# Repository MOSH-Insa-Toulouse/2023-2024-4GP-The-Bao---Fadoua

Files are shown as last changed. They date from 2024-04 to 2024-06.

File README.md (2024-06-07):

# 2023-2024-4GP-The-Bao---Fadoua

# 1. Description du projet  
Notre projet, inscrit dans l'UF "Du capteur au banc de test en open source hardware" de la 4ème année de Génie Physique à l’INSA Toulouse, vise à concevoir, fabriquer et caractériser un capteur de contrainte innovant utilisant une approche low-tech basée sur des capteurs en graphite. S'inspirant des travaux de chercheurs dans le domaine des capteurs, notre objectif est de développer un système de mesure complet, intégrant un shield Arduino avec un circuit analogique incluant un amplificateur transimpédance et des filtres, ainsi qu'une interface utilisateur via un écran OLED et une communication sans fil avec une application Android via un module Bluetooth. Nous avons également créé un banc de test pour évaluer les performances du capteur, en mesurant sa variation de résistance en fonction de la déformation induite par différents crayons graphites. Ces travaux aboutiront à la rédaction d'une datasheet détaillée du capteur, offrant ainsi une solution open source pour la mesure de contraintes basée sur une approche low-tech.

# 2. Livrables 
Les livrables de ce projet sont les suivants :
  
* Circuit Shield PCB avec Arduino UNO
     
   - Schéma électrique du circuit amplificateur transimpédance
   - Conception du PCB réalisée sous KiCad
   - Fabrication du PCB et soudure des composants
   - Intégration des éléments : amplificateur, module Bluetooth, écran OLED, encodeur rotatif
  
* Code Arduino     
   - Développement complet d'un code Arduino pour le fonctionnement du système.
   -  Fonctionnalités incluses :
   - Mesure de la déformation du capteur à base de graphite.
   -Transmission des données via le module Bluetooth.
   - Affichage des mesures sur l'écran OLED.
   - Utilisation de l'encodeur rotatif pour naviguer dans le menu de l'OLED.
  
* Application Android (APK)
* Banc de Test Dédié au Capteur
*  Datasheet Complète du Capteur
 ## 3. Matériel nécessaire
* Carte Arduino UNO
* Amplificateur opérationnel (LTC1050)
* Module Bluetooth (HC-05)
* Écran OLED
* Encodeur rotatif (KY-040)
* Flex Sensor
* 2 Résistance de 100kΩ
* 1 Résistance de 1kΩ
* 1 Résistance de 10kΩ
* Potentiomètre digital MCP-41050
* 2 Condensateurs 100nF
* 1 Condensateurs 1µF

 # 4. Electronique Analogique:
 
Le circuit amplificateur transimpédance est une composante essentielle de notre projet, car il permet de convertir le courant provenant du capteur de déformation à base de graphite en une tension mesurable. Composé de plusieurs éléments interagissant de manière précise, ce circuit garantit des mesures fiables et précises tout au long du processus.

Au cœur du circuit se trouve l'amplificateur opérationnel LTC1050, auquel le capteur de déformation est connecté à l'entrée inverseuse. Ce capteur, conçu pour ajuster sa résistance en fonction de la déformation, induit ainsi un changement de courant à travers la résistance de rétroaction R1.

La précision de nos mesures est assurée par le choix du LTC1050 pour ses faibles valeurs d'offset et de dérive. En complément, nous avons intégré trois étages de filtres au circuit pour optimiser le signal. Un filtre passe-bas à l'entrée (R1,C1) de 16 Hz atténue les hautes fréquences indésirables. Un second filtre passe-bas (R4, C2) de 1,6 Hz élimine le bruit de 50 Hz du réseau électrique. Enfin, un filtre final (R5,C3) de 1,6 kHz traite le bruit de l'ADC pour garantir des mesures précises et stables.



Chaque composant du circuit a été soigneusement sélectionné et dimensionné pour optimiser les performances. Des simulations approfondies sous LTSpice ont validé le fonctionnement du circuit avant la conception du PCB final. Des tests sur une breadboard ont confirmé sa fiabilité en conditions réelles, avec des mesures de résistance et de déformation du capteur réalisées pour évaluer sa précision.

La formule utilisée pour calculer la résistance du capteur de contrainte au graphite est la suivante :

      𝑅𝑠𝑒𝑛𝑠𝑜𝑟 = (1 +𝑅4/𝑅2) ∗ 𝑅1 ∗ (𝑉𝐶𝐶/𝑉𝐴𝐷𝐶) − 𝑅1 − 𝑅3

<h2> Modélisation du capteur:
     
</br>

  

<h2> Voici le schéma du circuit simulé sur le logiciel LTSpice :

</br>

   

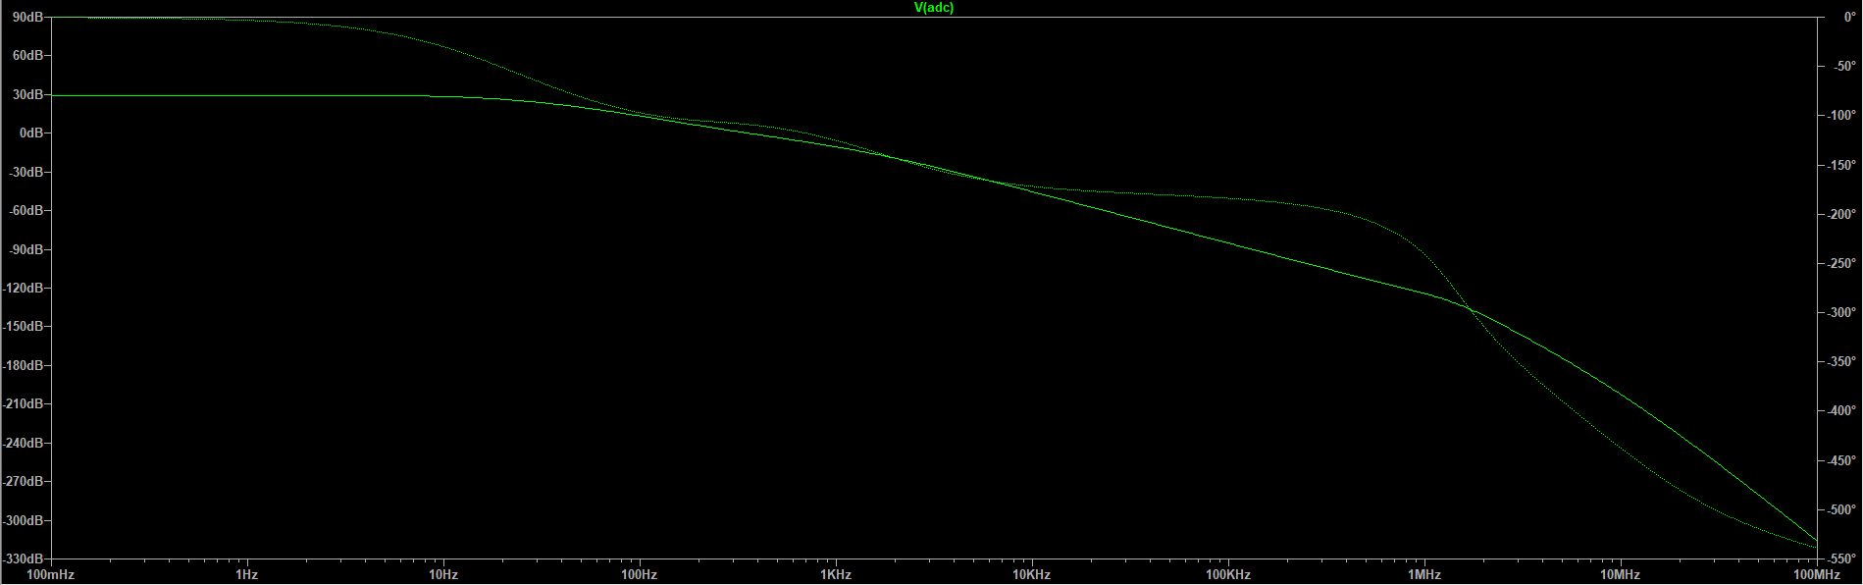
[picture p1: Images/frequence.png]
   
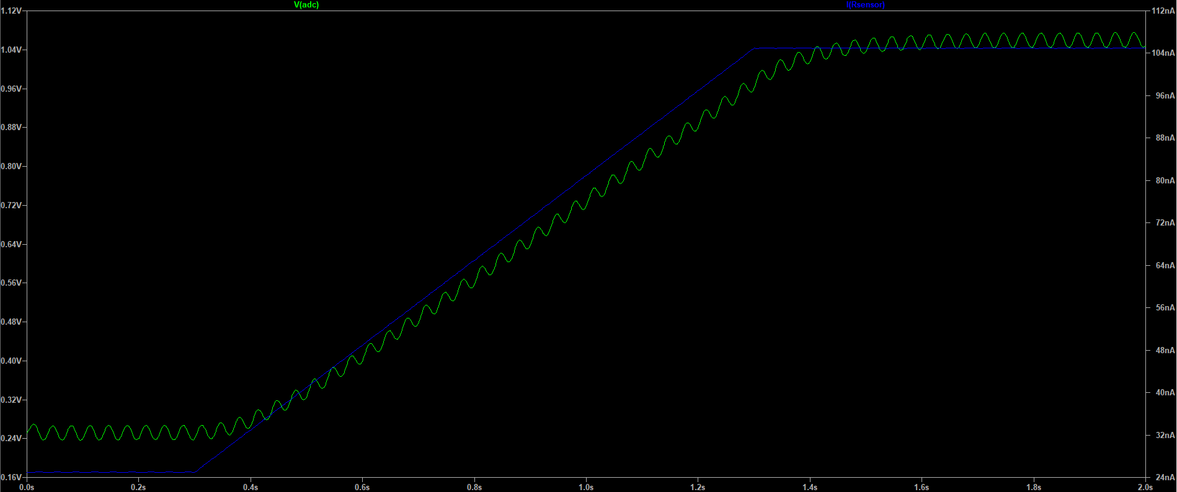
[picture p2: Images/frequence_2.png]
   

 # 5. Progamme Arduino:
 Notre programme d'Arduino nous permet de mesurer la résistance des deux capteurs (Flex sensor et Capteur en graphine) à partir de la valeur tension mesuré par la composant ADC dans l'Arduino. Il affiche ensuite sur l'écran OLED les valeurs de résistance sélectionnées en tournant l'encodeur rotatoire. 

Dans notre programme, on a également établi la connexion entre la module bluetooth et l'application mobile. C'est à dire qu'on a créé les protocols de communication entre eux. Vous pouvez voir dans le diagramme ci-dessous que le module Bluetooth est utilisé pour recevoir les commandes de l'application mobile et lui envoyer les données demandées. L'Arduino va recevoir ces commandes pour envoyer des données à l'application mobile ou régler la résistance du potentiomètre numérique afin de changer le gain de l'amplificateur. 

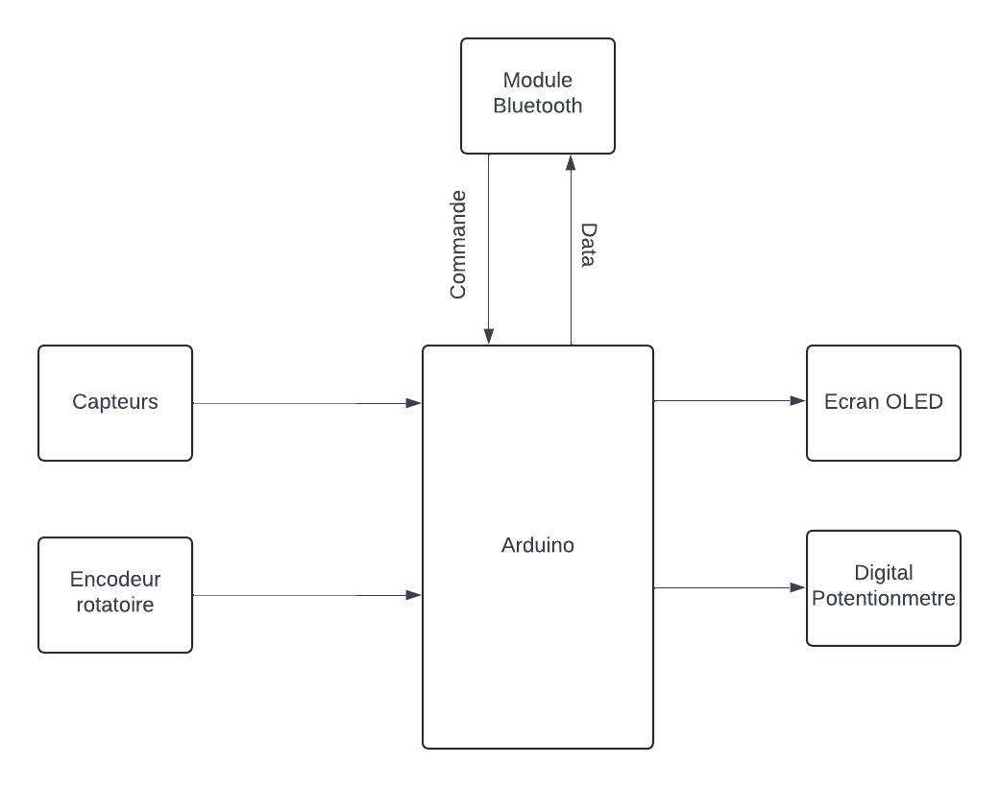
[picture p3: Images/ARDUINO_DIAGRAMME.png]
   

 # 6. KiCad:
 ## Réalisation de la Schématique de Shield
Dans cette étape de réalisation de la schématique du shield, notre objectif principal était de concevoir un circuit électronique fonctionnel pour notre projet. Nous avons choisi le logiciel KiCad comme plateforme de conception et nous nous sommes basés sur le modèle d'une carte Arduino Uno pour assurer la compatibilité. Après avoir identifié tous les composants nécessaires pour notre projet, nous avons ensuite procédé à la création de notre propre bibliothèque d'empreintes personnalisées pour les composants manquants. Cette démarche nous a permis d'adapter notre conception à nos besoins spécifiques et d'assurer une intégration optimale des composants dans notre schéma électrique.
Voici les symboles et empreintes des composants que nous avons créés dans le logiciel KiCad :

### **Module Bluetooth (HC-05)**
  
<div class="column" align="center">

        
</div>

### **Encodeur rotatif (KY-040)**
<div class="column" align="center">

           
</div>

### **Écran OLED**
<div class="column" align="center"> 

             
</div>

### **Flex Sensor**
  <div class="column" align="center">

               
</div>

###  **Potentiomètre digital MCP-41050**

<div class="column" align="center">




</div>

Après avoir créé les schémas et les empreintes pour chaque composant, nous avons assemblé le schéma électrique complet du shield Arduino en reliant les broches des composants avec celles de la carte Arduino.

<div class="column" align="center">

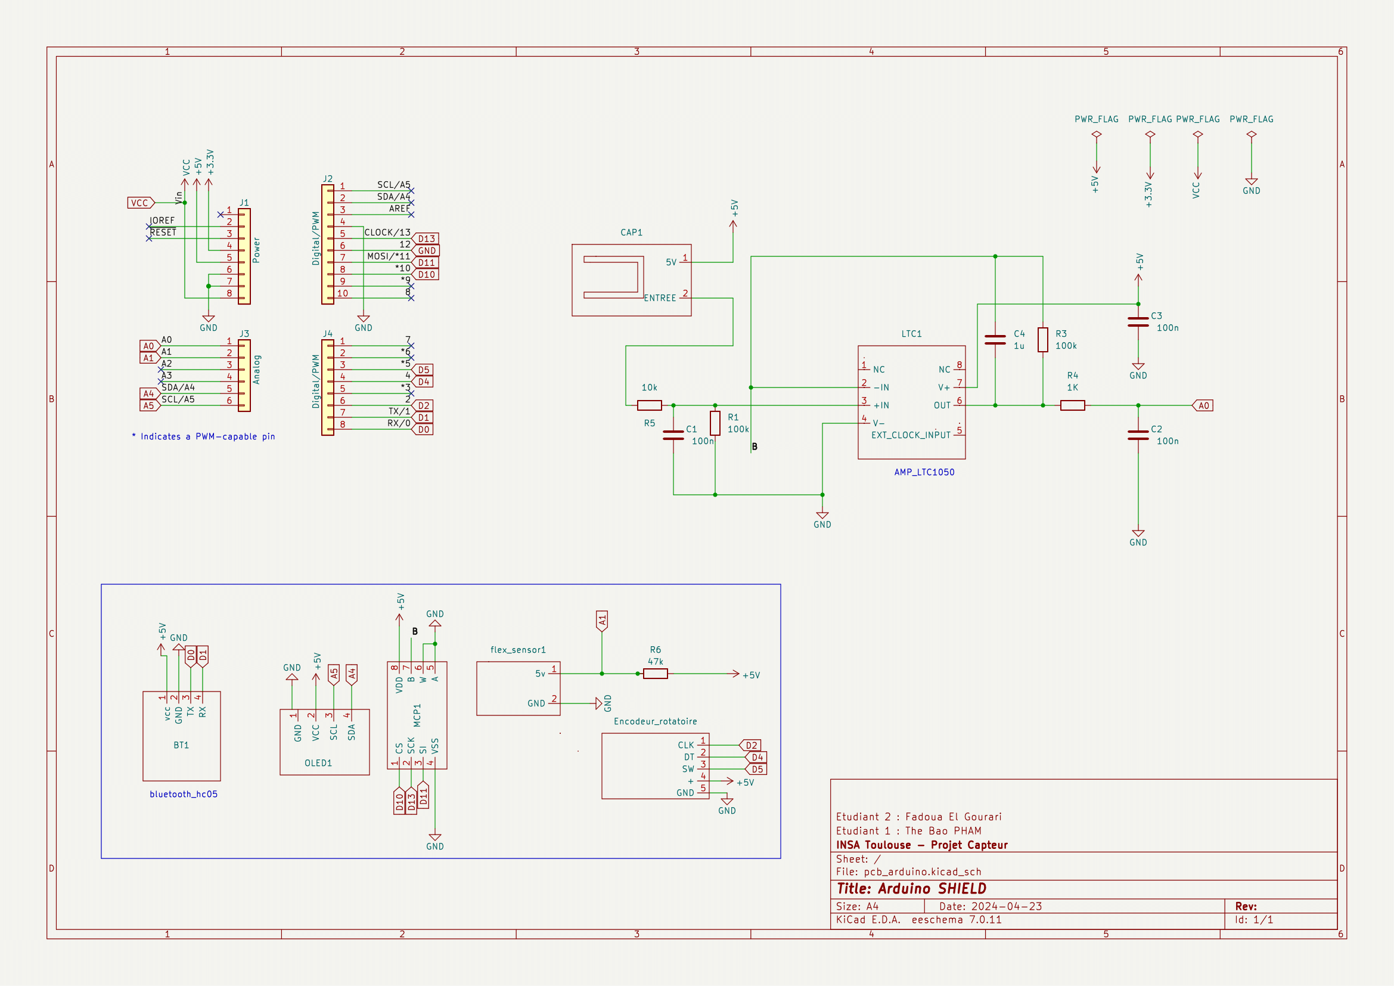
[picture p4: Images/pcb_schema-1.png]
   

</div>

### Réalisation de la Schématique du PCB et visualisation 3D
Dans cette étape, nous avons réalisé le routage de notre circuit en intégrant les composants sur le PCB, tout en veillant à limiter les distances entre les composants et leurs pins, conformément aux directives de nos enseignants référents, M. Jérémie Grisolia et Mme Catherine Crouzet. Nous avons respecté des paramètres spécifiques tels que la largeur des pistes, la largeur d'isolation des pistes et les dimensions des trous pour chaque composant, afin d'assurer la conformité de notre conception. Une fois cette phase terminée, nous avons ajouté le plan de masse pour relier les pistes au GND.

Les paramètres spécifiques suivants ont été respectés :
* Taille du trou de perçage pour l'écran OLED,Flex Sensor,le module Bluetooth et l'encodeur rotatoire, l'AOP et le potentiomètre digital = 1mm
* Taille du trou de perçage pour les résistances et les capacités = 0.8 mm
* Dimensions du trou pour le support de l'AOP ,l'écran OLED,Flex Sensor,le module Bluetooth et l'encodeur rotatoire,le potentiomètre digital (pad n°1 rectangulaire et les autres pins sont ovales) = 2 mm * 2.5 mm
* Largeur d'isolation des pistes = 0.8 mm
* Taille du trou de perçage du via = 0.8 mm
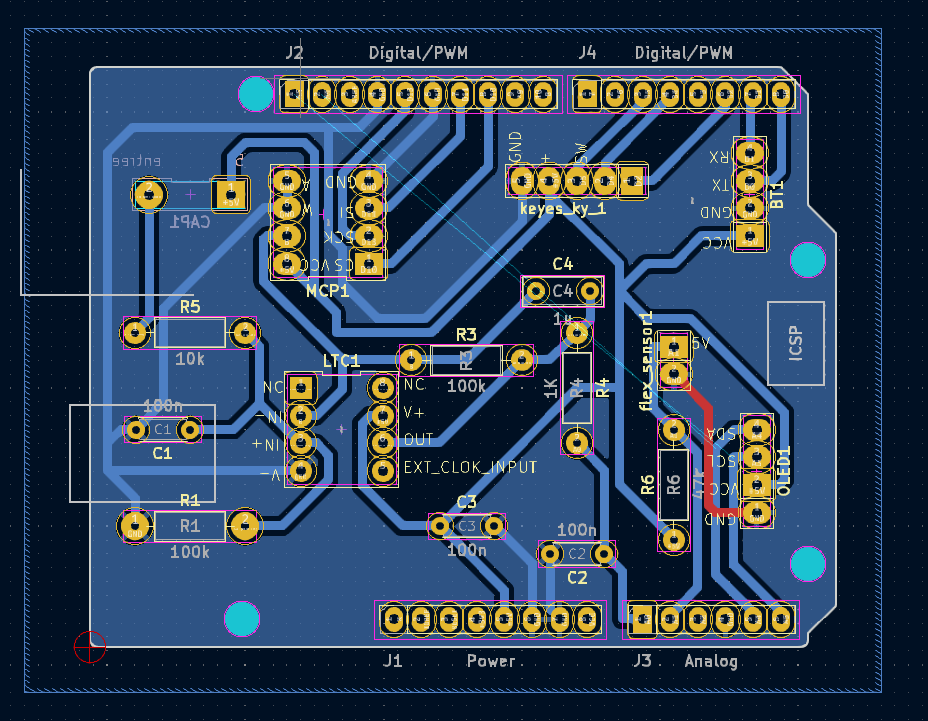
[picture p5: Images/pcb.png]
   

### **Visualisation 3D**
  
Après avoir réalisé le PCB, le téléchargement des modèles de composants sur le site "grabcad.com", qui n'étaient pas fournis par KiCad, s'est avéré très utile. Cela nous a permis d'obtenir un modèle 3D de notre PCB final. Nous avons ainsi pu vérifier que les positions des composants étaient correctes avant de passer à l'étape de l'impression du circuit.
  
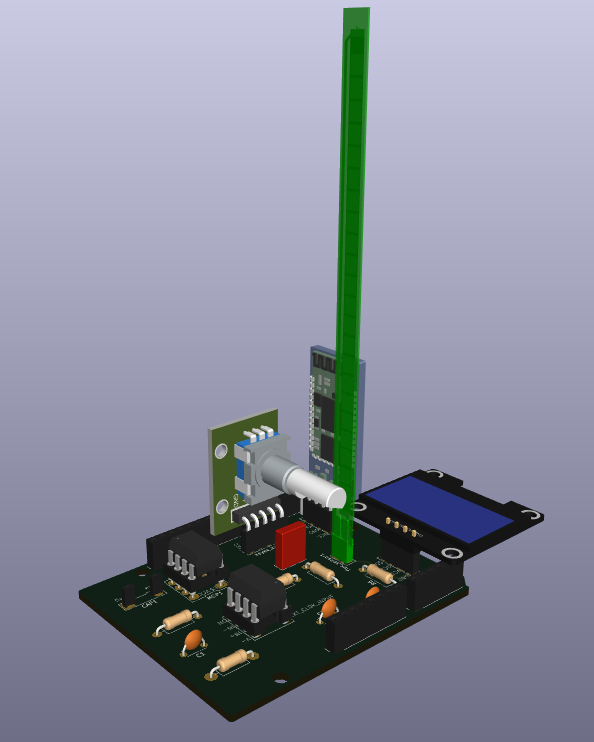
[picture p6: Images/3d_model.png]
  

### **Fabrication du shield PCB:**
  
Dans le cadre de notre projet, nous avons fabriqué un circuit imprimé (PCB) au sein des départements de Génie Électrique et Informatique et de Génie Physique de l'INSA Toulouse. La fabrication a commencé par la modélisation du circuit sur le logiciel KICAD, suivie de l'impression de cette modélisation sur du papier calque. Nous avons ensuite réalisé une insolation UV de notre plaquette d’époxy recouverte d’une fine couche de cuivre (environ 60 µm) pendant une dizaine de minutes, en utilisant le calque comme masque. La résine non exposée aux UV a été retirée avec un révélateur, puis la plaquette a été plongée dans un bain de perchlorure de fer pendant environ 7 à 9 minutes. Cette étape a permis de dissoudre le cuivre non protégé et de révéler les pistes du circuit. Enfin, un rinçage à l'acétone a été effectué pour éliminer les dernières traces de résine, nous permettant ainsi d'obtenir notre PCB conforme à la modélisation initiale. Cette réalisation a été possible grâce à l'aide précieuse de Cathy, assurant la qualité et la précision du produit final.

<div class="column" align="center">

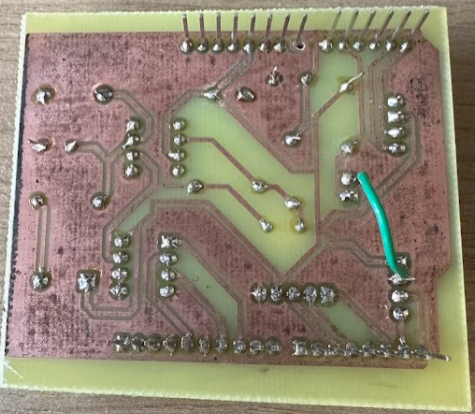
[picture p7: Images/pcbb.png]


 </div>

### Assemblage des composantes :
Une fois le PCB fabriqué, nous avons procédé à l'assemblage des composants, ce qui implique le perçage du PCB et la soudure des éléments électroniques. Conformément aux spécifications de notre projet, deux tailles de trous ont été prévues dans la conception sur KICAD : des trous de 0,8 mm de diamètre pour les composants tels que les amplificateurs opérationnels (AOP) LTC1050, les résistances et les capacités, et des trous de 1 mm de diamètre pour les broches de connexion de la carte Arduino Uno et les headers des différents modules (OLED, Bluetooth, encodeur rotatif...). À l'aide d'une perceuse électrique, nous avons percé le PCB aux emplacements désignés pour insérer les composants. Ensuite, nous avons soudé les composants en place en utilisant de l'étain pour assurer des connexions électriques solides et fiables. Ce processus d'assemblage a permis d'obtenir un shield opérationnel, prêt à être intégré dans notre système.

<div class="column" align="center">


</div>

 # 7. Application mobile:
Pour ce projet, nous avons développé une application mobile sur MIT App Inventor qui se connecte au module Bluetooth du capteur. Cette application dispose d'une interface unique permettant d'acquérir les données du capteur en temps réel, de les visualiser sur un graphique dynamique et de enregistrer le graphique dans notre téléphone ainsi que de régler le gain de l'amplificateur.

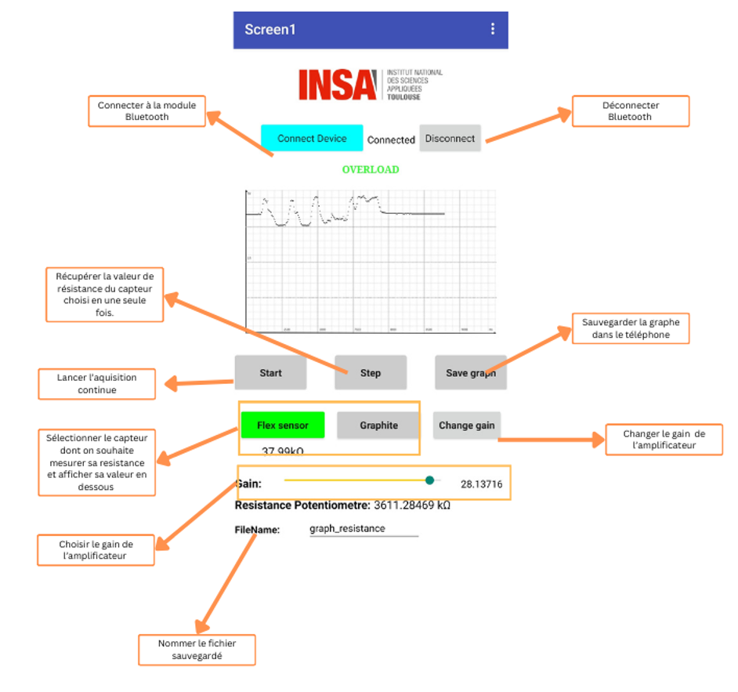
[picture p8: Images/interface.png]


# Initilisation de programme:
<h3>Au début, nous avons déclaré les variable globale utilisé dans le programme de l'application

<br />












Initialiser le programme 

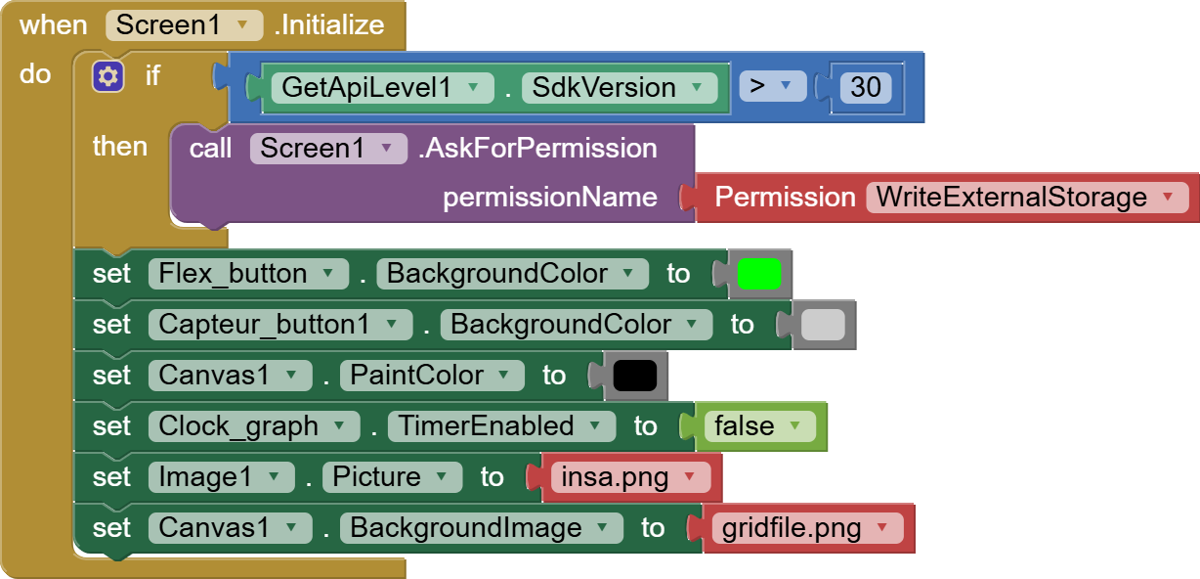
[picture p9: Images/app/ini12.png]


# Composantes dans l'interface:
## "Connect Device" 

Ce bouton est utilisé pour choisir la module bluetooth qu'on veut le connecter


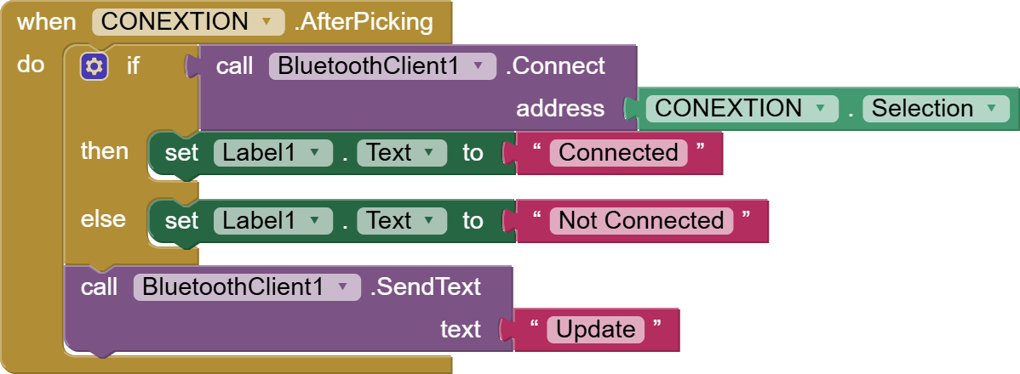
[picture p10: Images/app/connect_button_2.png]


## Statut de connexion bluetooth:
Étiquette représentant la statut de connexion Bluetooth. 

## "Disconnect" 
 Ce bouton est utilisé pour déconnecter la bluetooth.



## Zone graphique
 
On a utilisé la composante "Canvas" dans MIT pour visualiser le signal

Dans cette zone, le signal de tension mesuré est visualisé en fonction du temps. Chaque fois que le potentiel est mesuré, il est représenté par un point sur le graphique.

Concernant le fond du graphique, il est représenté en échelle linéaire. Chaque petit carré correspond à 500 ms en horizontale et à 0,25 V en verticale.

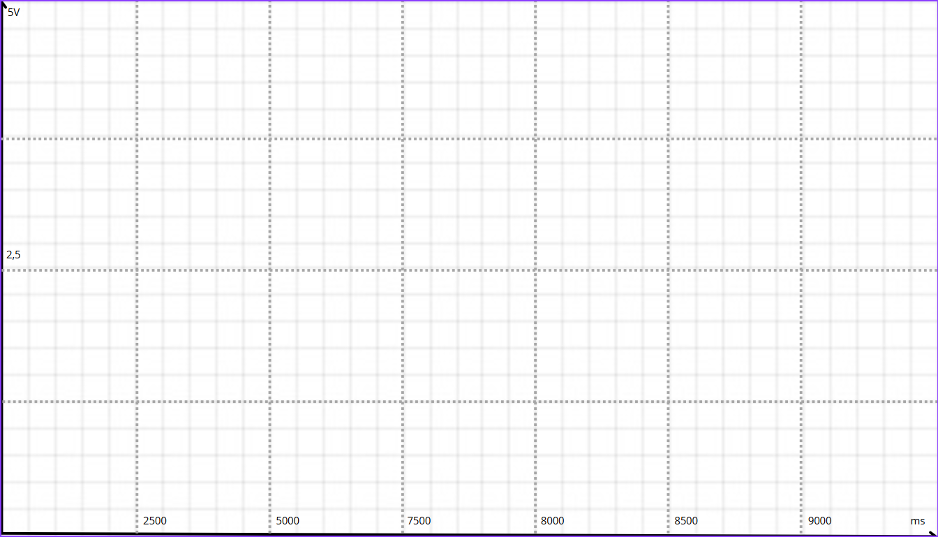
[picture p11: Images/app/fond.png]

Figure 3: Le fond de la graphique

## Statut "Overload"

Parce que, l'Arduino ne mesure que jusqu'à 5V. En outre, avec un gain variable d'ampificatuer, la tension mesurée peut facilement devenir saturée. Ce phénomètre peut être observé lorsque le signal est visualisé dans la graphique. Pourtant, si on prendla valeur de résistance en seul fois, la saturation causerait un mal calcul de la résistance de capteur

Dans notre programme d'Arduino, nous avons défini une limitation de tension mesurée pour éviter la sarturation. La limitation de tension est 0 - 4.8V. Pour pouvoir détecter la saturation, une fois que la tension mesurée dépasse cette limite, l'Arduino vas envoyer un message qui contient une chaine des charactères "over". Si la message recus contien ce mot, l'étiquette "Overload" devient rouge; sinon, elle reste verte.



## "Start"
Lancer l'acquitiion de tension continue avec le délai entre deux acquisitions est 100ms

Une fois ce bouton est appuyé, il désactivera les boutons restants pour éviter d'être pressé par erreur et d'affecter l'acquisition. Pour arrêter l'acquisition, appuyez une nouvelle fois sur ce bouton.

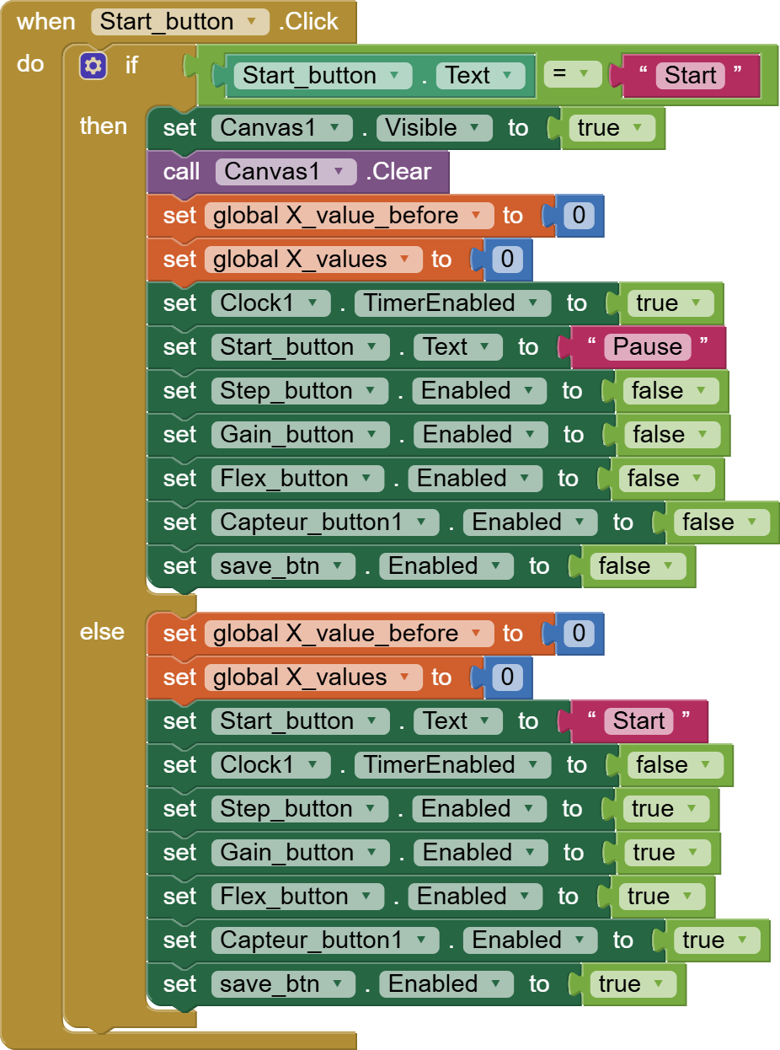
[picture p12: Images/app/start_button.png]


Pour pouvoir récupérer automatiquement des données, nous commandons séquentiellement Arduino de nous evoyer les données. Pour cela, nous avons utilisé le composante "Clock"dans MIT

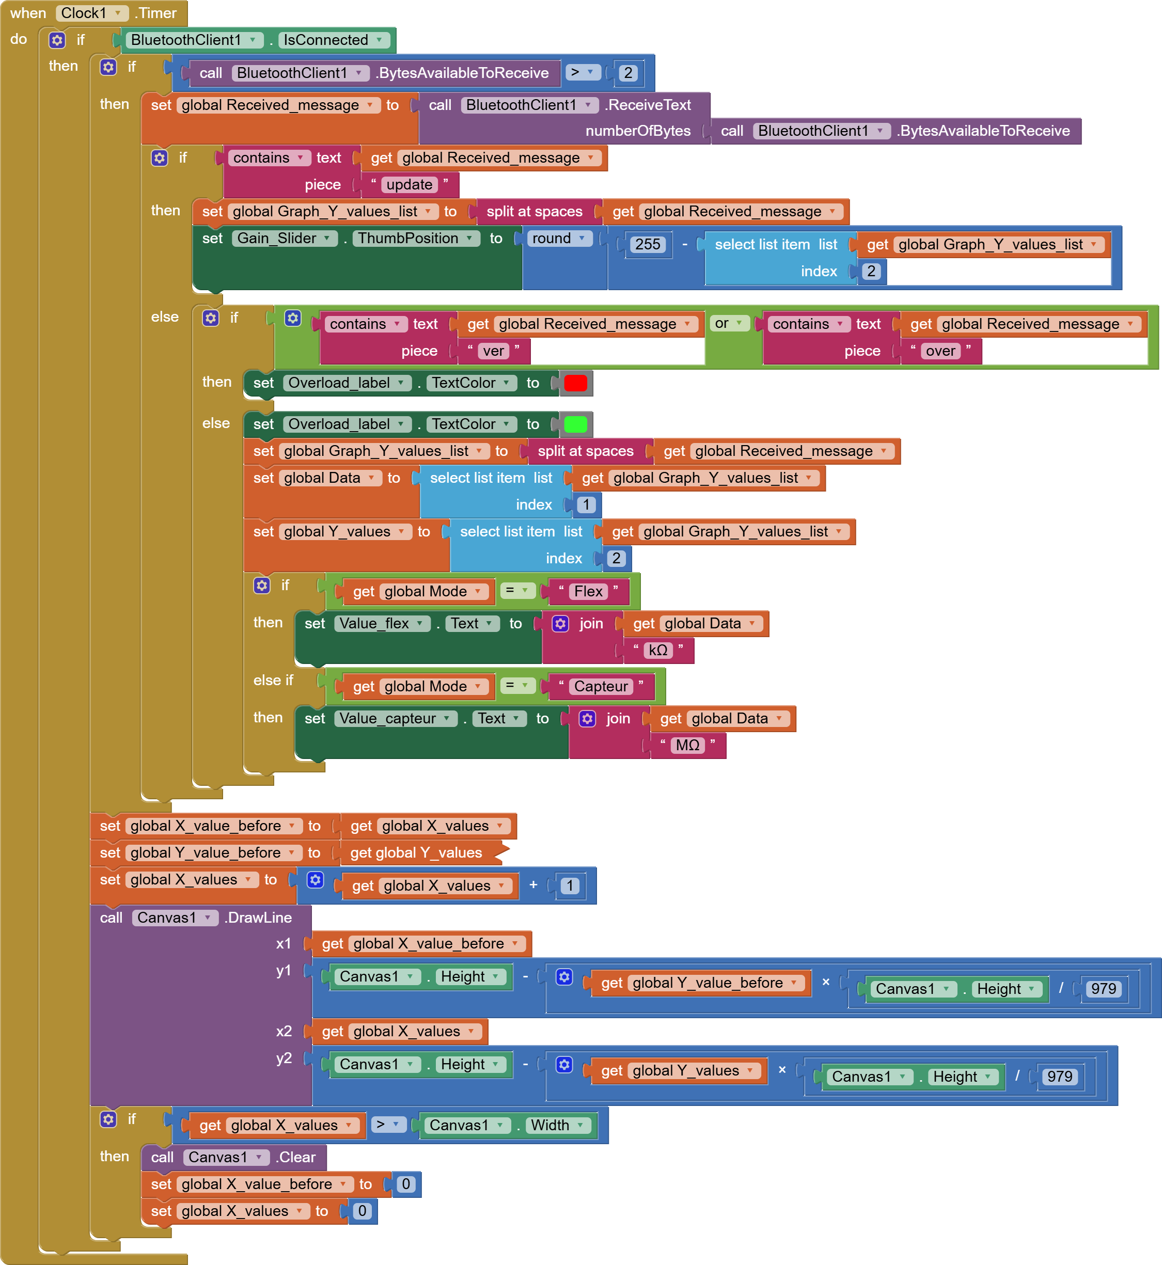
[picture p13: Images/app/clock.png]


## "Step"
Ce bouton sert à récupérer la valeur de résistance du capteur sélectionné en une seule fois.

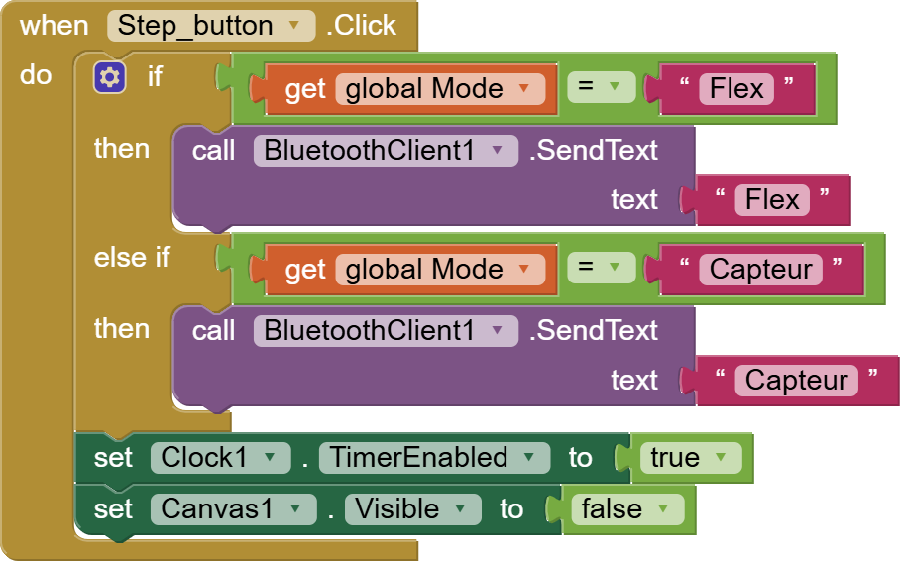
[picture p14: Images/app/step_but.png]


## "Save graph"

"En appuyant sur ce bouton, nous pouvons enregistrer le graphique dans le dossier "Photos" de notre téléphone au format .png. Pour cela, au début, on sauvegarde le graphe dans une mémoire externe de téléphone et nous le déplacons dans la dossier Photos de téléphone à l'aide d'extention "Taifuntool" 

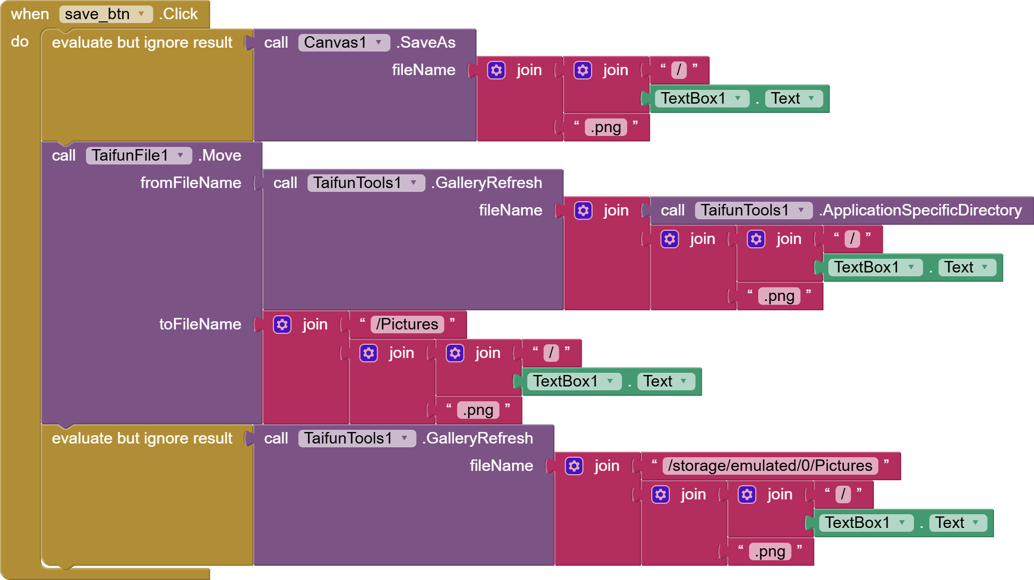
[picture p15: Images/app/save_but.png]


## "Flex sensor" et "Graphite"
Ces boutons permettent de choisir le capteur dont on veut afficher la valeur.
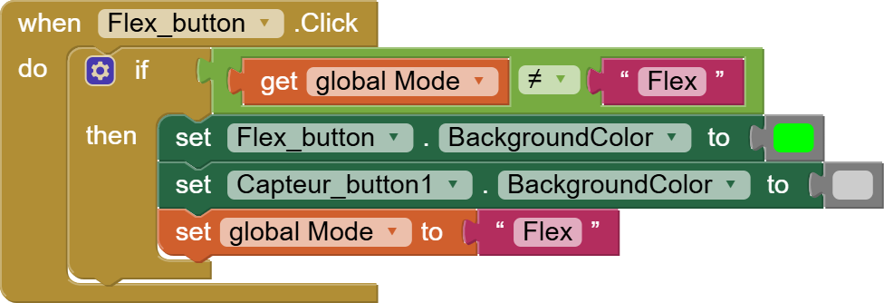
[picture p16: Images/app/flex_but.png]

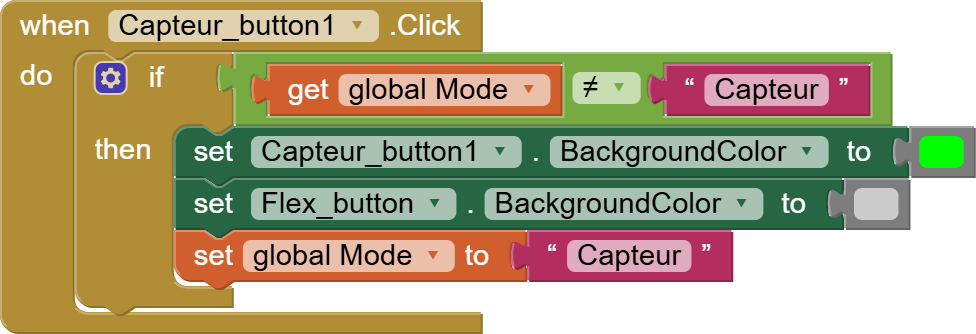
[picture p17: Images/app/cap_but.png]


## "Gain" Slider
Il utilisé pour régler le gain de l'amplificateur en changant la résistance de potentiomètre numérique. En utilisant ce curseurs, on peut choisir le gain qu'on souhaite. 

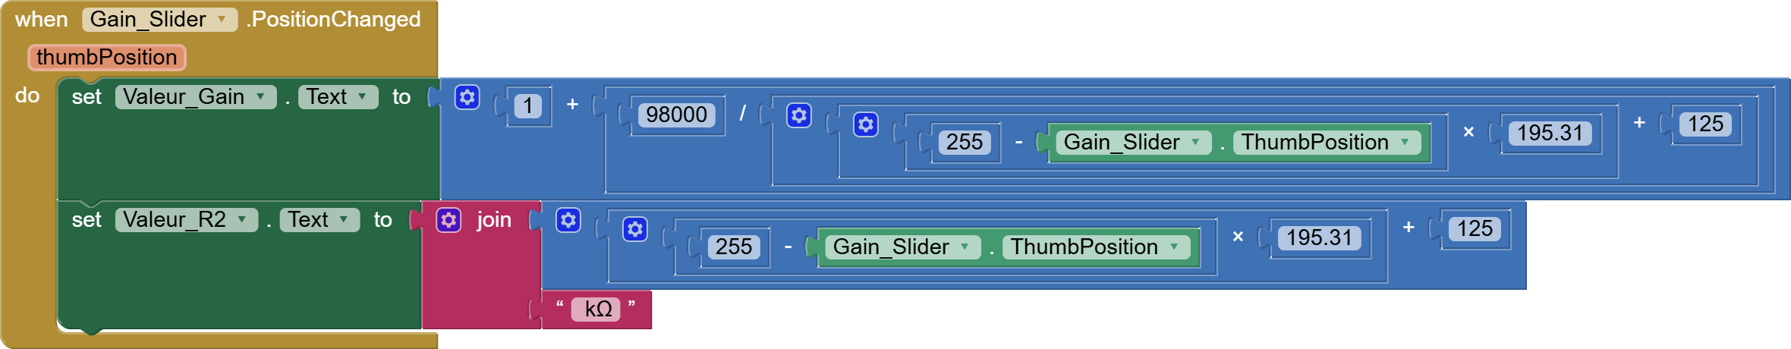
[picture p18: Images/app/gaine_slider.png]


## "Change gain"

Un fois qu'on appuie sur ce bouton, on envoie un commande à l'Arduino pour changer le gain de l'amplificateur

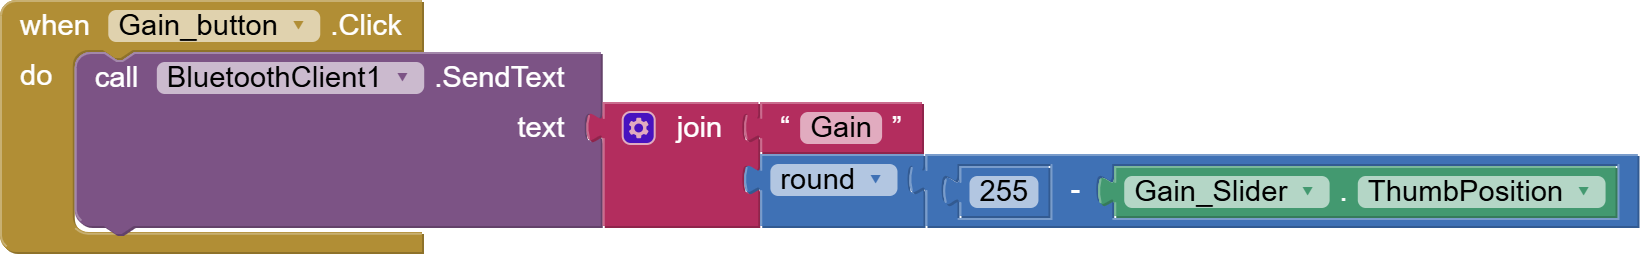
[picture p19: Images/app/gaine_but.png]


## "Resistance Potentiometre"

Ce bouton sert à lire la résistance de potentiomètre

## "File Name" 

Ce composante est utilisé pour nommer la graphe qu'on va sauvegarder

 # 8. Mesures et résultats :
 
Pour étudier les caractéristiques du capteur, nous avons utilisé un banc d'essai composé de sept demi-cylindres disposés de manière séquentielle, du plus petit au plus grand. Le diamètre de chaque demi-cylindre variait de 2 cm à 5 cm, avec un pas de 0,5 cm.

<p align="center">



</p> 

Notre objectif était d'analyser la résistance du capteur en fonction de sa déformation induite en le pliant sur ces cylindres. Le degré de déformation a été calculé à l'aide de la formule  
 
      𝜀 = 𝑒 / (2r) 

Où **𝜀** représente la déformation, **e** désigne l'épaisseur de la feuille de papier, et **r** représente le rayon de chaque demi-cylindre. Pour l'épaisseur **e**, nous avons choisi une valeur de 0,16 mm, correspondant au grammage d'une feuille avec une densité de 140 g/m². 

Notre expérimentation a consisté à mesurer la déformation des capteurs sous compression et sous tension afin d'évaluer de manière exhaustive leurs caractéristiques de performance.
 
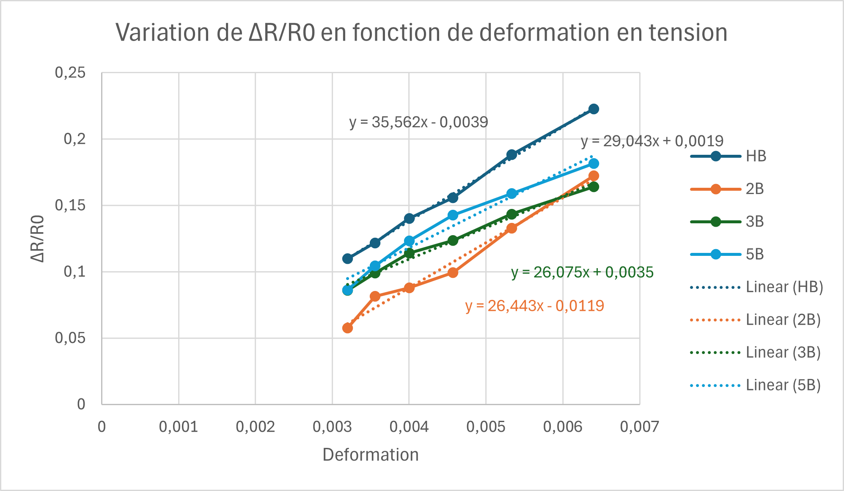
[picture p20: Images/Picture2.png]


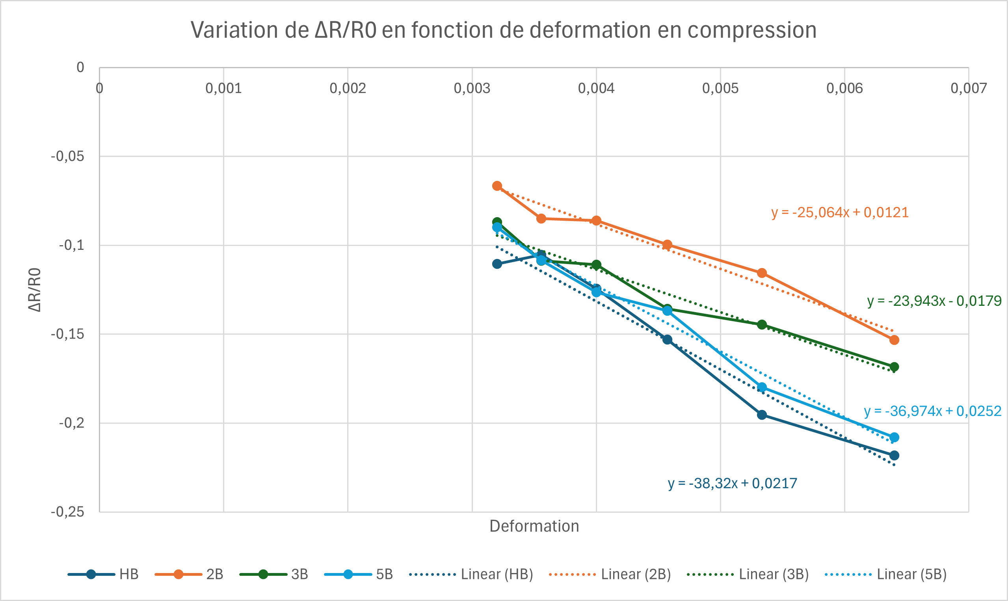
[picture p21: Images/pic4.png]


# 9. Remerciement et contact

Nous souhaiterions remercier Catherine Crouzet qui nous a beaucoup aidé à comprendre et à solutionner nos problèmes tout au long du projet. Nous adressons également nos remerciements à Jérémie Grisolia et Arnaud Biganzoli pour leur aide à la programmation Arduino et Github. 

Pour toutes questions ou informations supplémentaires, vous pouvez nous contacter par mail :

The Bao PHAM: pha@insatoulouse.fr
Fadoua EL GOURARI : elgourar@insa-toulouse.fr

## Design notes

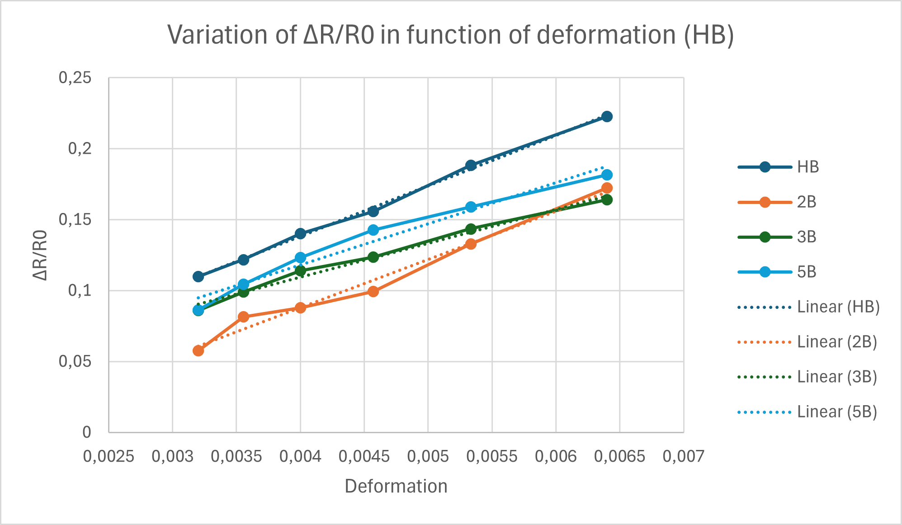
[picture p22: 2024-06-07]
Images/Picture1.png

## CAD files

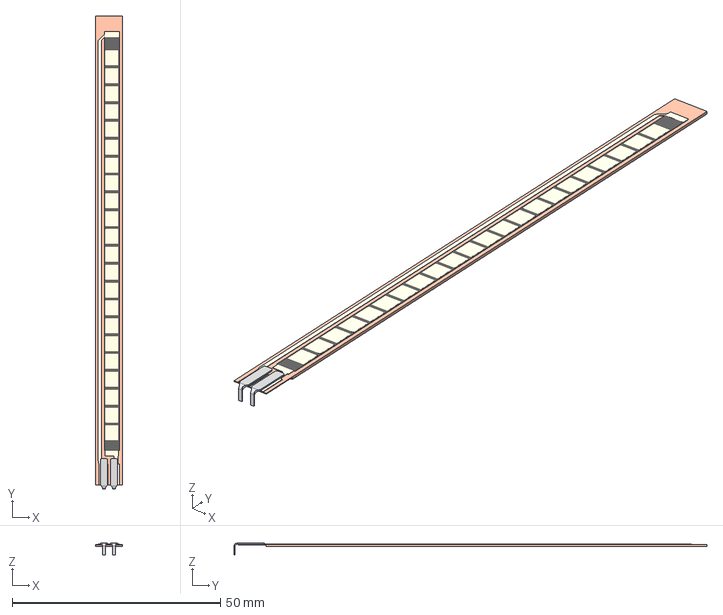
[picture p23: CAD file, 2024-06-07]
3d model/flex-sensor-fs-l-0095-103-st-1.snapshot.2/FS-L-0095-103-ST - Assembly.stp
6.45 x 113.5 x 2.77 mm
FS-L-0095-103-ST - Base
FS-L-0095-103-ST - Top

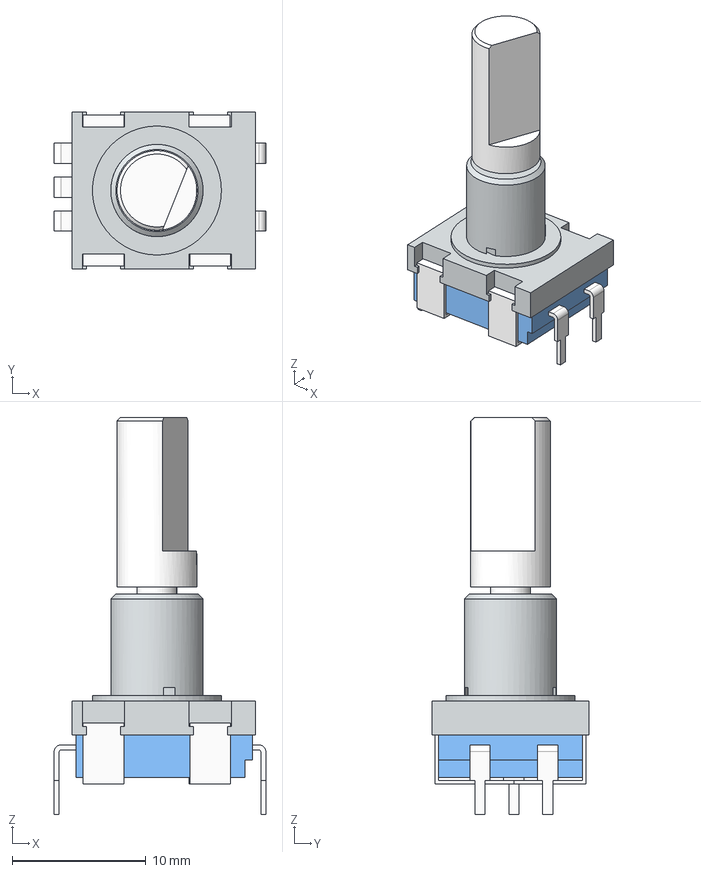
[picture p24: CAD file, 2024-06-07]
3d model/rotary-encoder-1.snapshot.8/rotary encoder step files/Step Files/Rotary Encoder without pcb Assembly.stp
15.8 x 11.8 x 29.7 mm
mtg flange
body_encoder
pins_encoder body_2 x 5
shaft_encoder

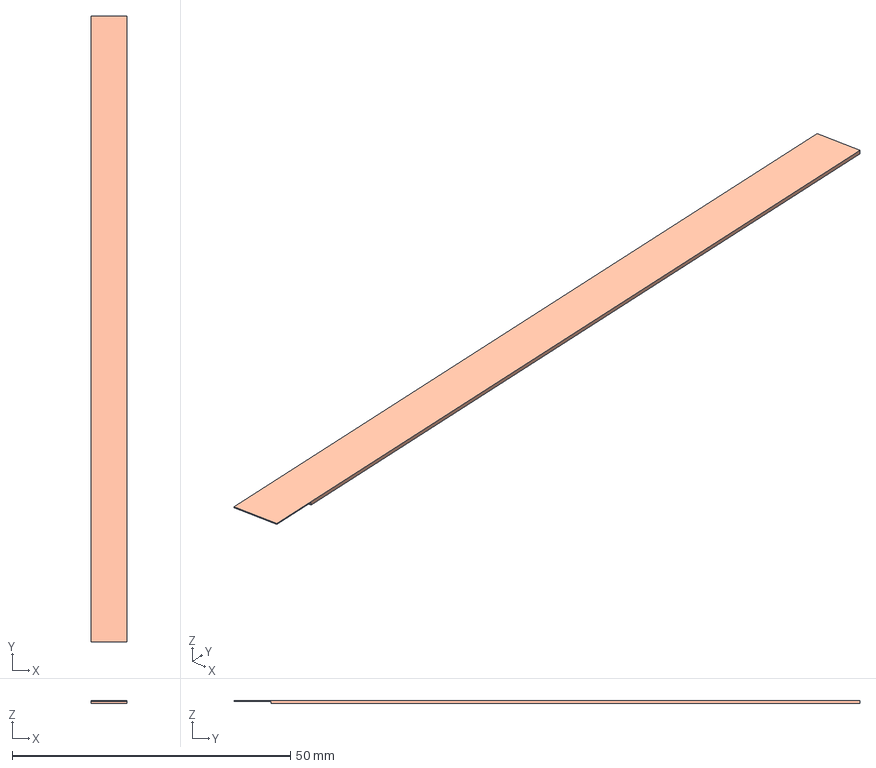
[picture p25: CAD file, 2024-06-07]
3d model/flex-sensor-fs-l-0095-103-st-1.snapshot.2/SolidEdge/FS-L-0095-103-ST - Base.stp
6.45 x 112.4 x 0.483 mm

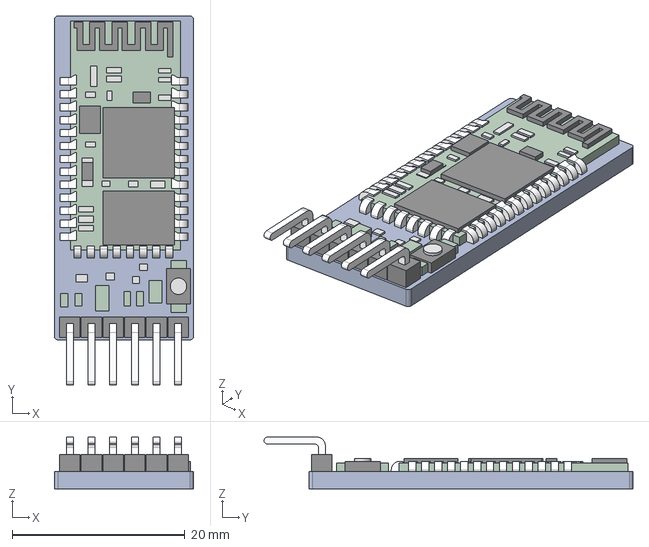
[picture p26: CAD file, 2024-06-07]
3d model/hc-05-bluetooth-module-2.snapshot.1/HC_05 Blue Tooth Module.stp
16.1 x 42.7 x 6.00 mm

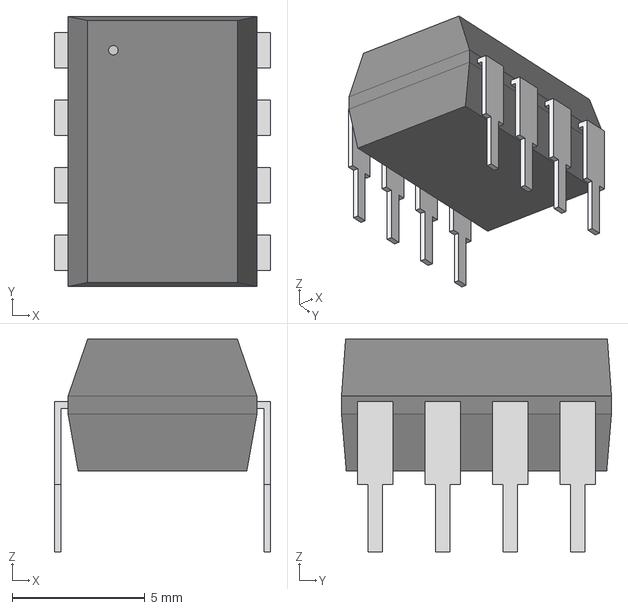
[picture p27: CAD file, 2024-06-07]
3d model/MCP41050_E_P/PDIP8_300MC_MCH.step
8.13 x 10.2 x 8.00 mm

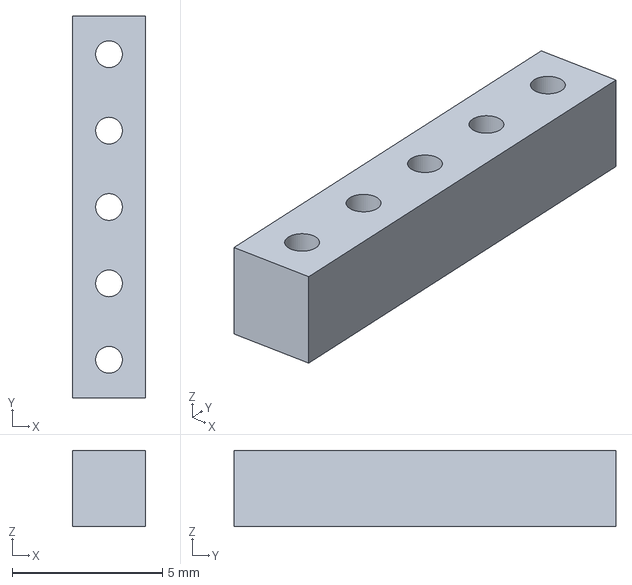
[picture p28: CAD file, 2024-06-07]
3d model/rotary-encoder-1.snapshot.8/rotary encoder step files/Step Files/5 pin header.stp
2.41 x 12.7 x 2.54 mm

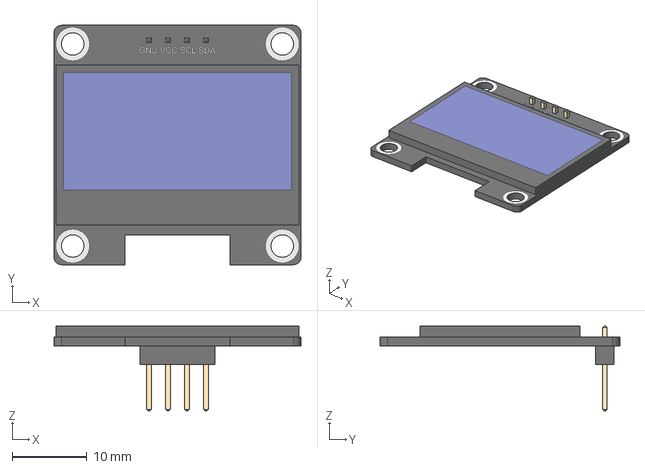
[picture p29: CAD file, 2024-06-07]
3d model/ssd1315-zhongjingyuan-1-29-oled-module-1.snapshot.1/SSD1315 ZhongJingYuan v1.step
33.0 x 32.0 x 11.3 mm

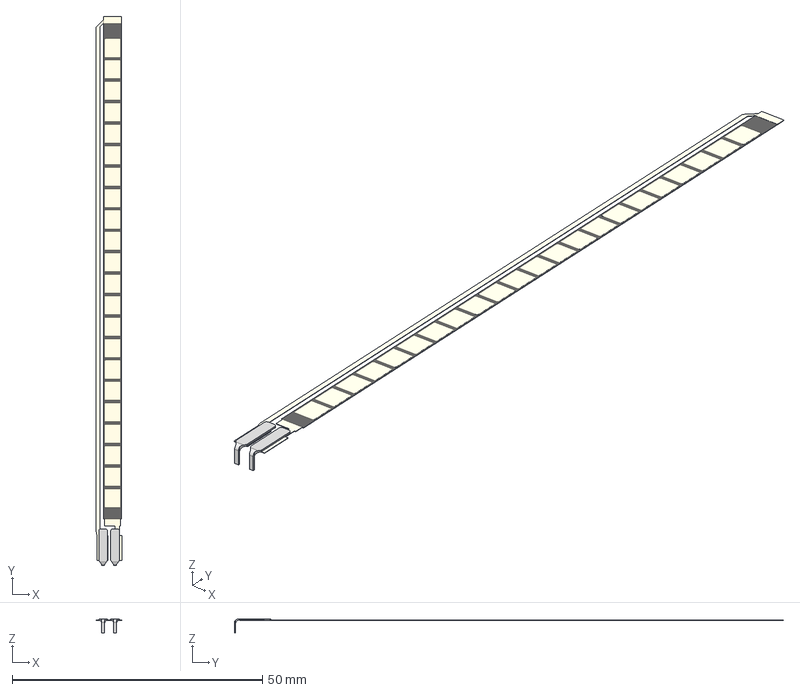
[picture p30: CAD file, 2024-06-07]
3d model/flex-sensor-fs-l-0095-103-st-1.snapshot.2/SolidEdge/FS-L-0095-103-ST - Top - Right.stp
5.17 x 109.7 x 2.77 mm

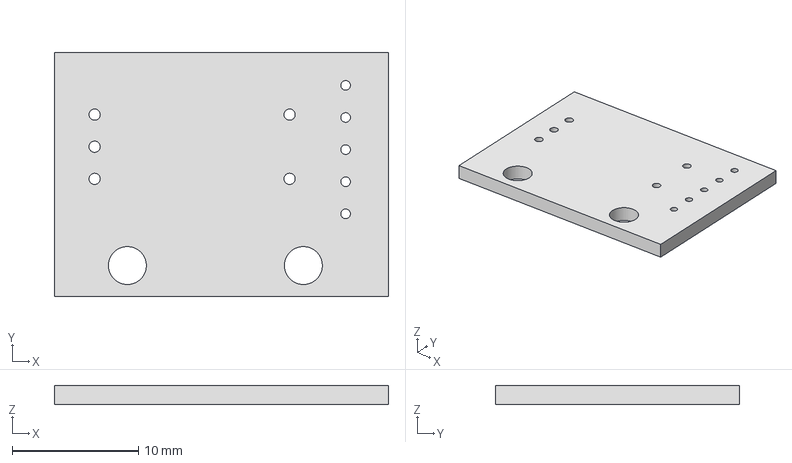
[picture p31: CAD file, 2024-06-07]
3d model/rotary-encoder-1.snapshot.8/rotary encoder step files/Step Files/pcb.stp
26.4 x 19.3 x 1.52 mm

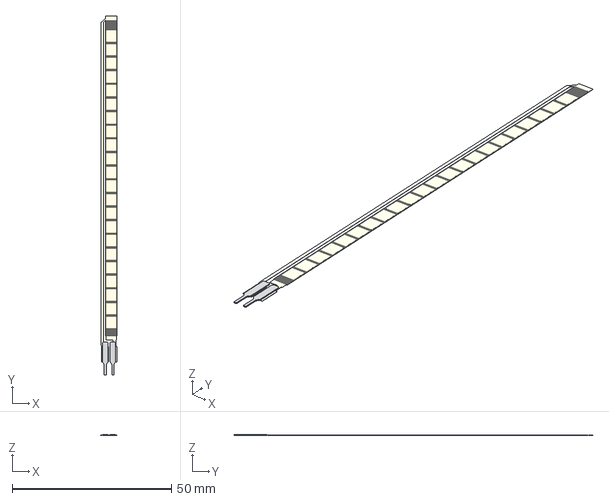
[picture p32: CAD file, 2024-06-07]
3d model/flex-sensor-fs-l-0095-103-st-1.snapshot.2/SolidEdge/FS-L-0095-103-ST - Top.stp
5.17 x 112.8 x 0.292 mm

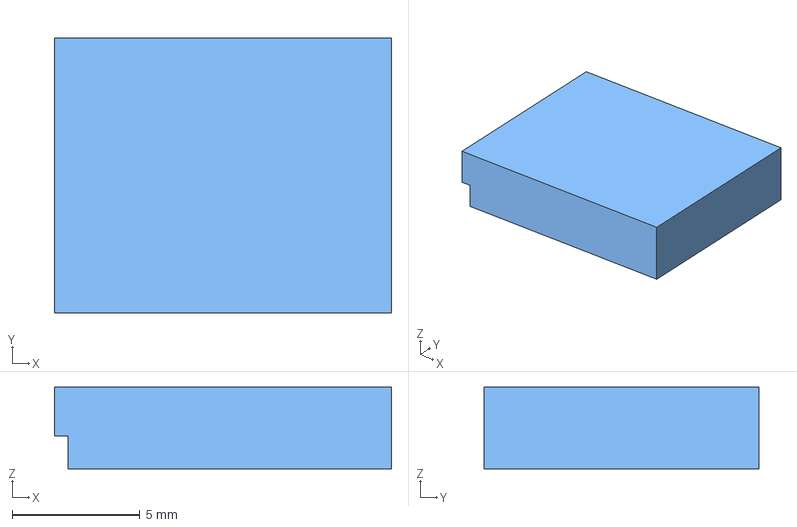
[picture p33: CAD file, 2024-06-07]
3d model/rotary-encoder-1.snapshot.8/rotary encoder step files/Step Files/body_encoder.stp
13.2 x 10.8 x 3.20 mm

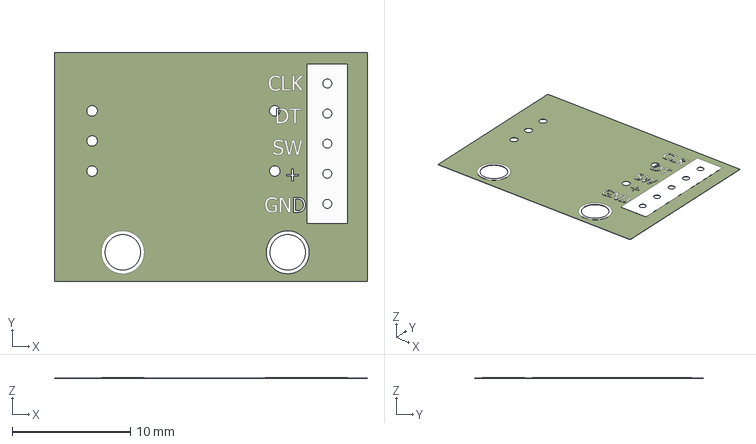
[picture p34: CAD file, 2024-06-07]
3d model/rotary-encoder-1.snapshot.8/rotary encoder step files/Step Files/decal_encoder.stp
26.4 x 19.3 x 0.0508 mm

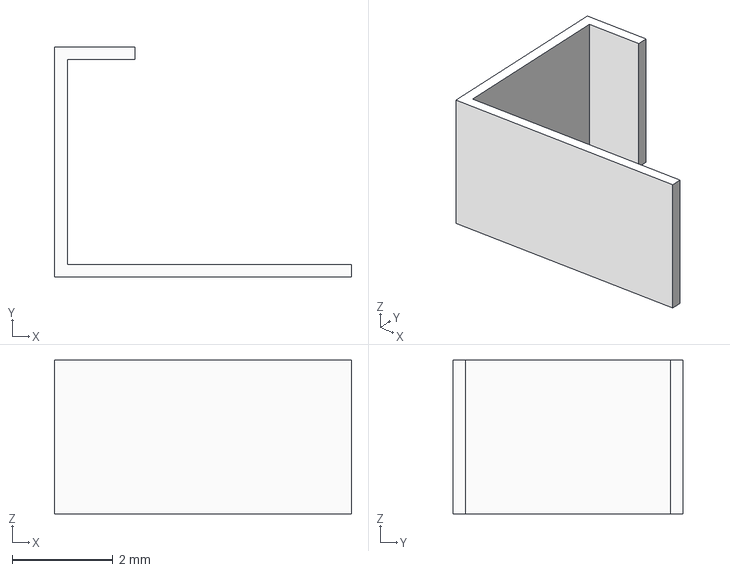
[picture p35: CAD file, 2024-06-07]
3d model/rotary-encoder-1.snapshot.8/rotary encoder step files/Step Files/body_2.stp
5.89 x 4.57 x 3.05 mm

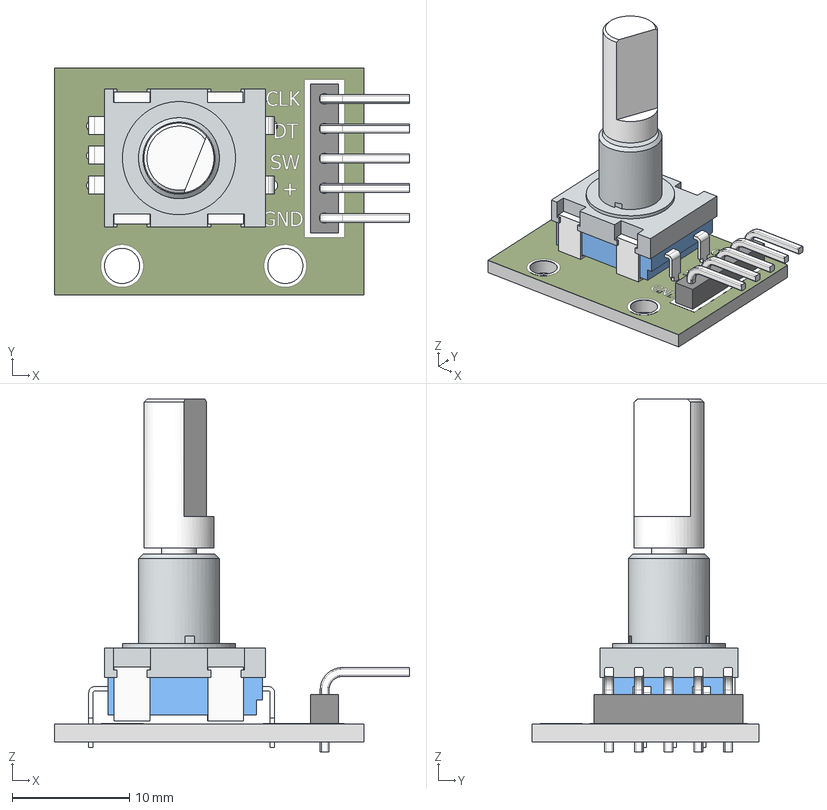
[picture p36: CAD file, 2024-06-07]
3d model/rotary-encoder-1.snapshot.8/rotary encoder step files/Step Files/rotary encoder_chesr_2013.stp
30.3 x 19.3 x 30.1 mm

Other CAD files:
3d model/rotary-encoder-1.snapshot.8/rotary encoder step files/Step Files/mtg flange.stp
3d model/rotary-encoder-1.snapshot.8/rotary encoder step files/Step Files/90d pin_header.stp
3d model/rotary-encoder-1.snapshot.8/rotary encoder step files/Step Files/pins_encoder body_2.stp
3d model/hc-05-bluetooth-module-2.snapshot.1/HC_05 Blue Tooth Module.ipt
3d model/rotary-encoder-1.snapshot.8/Rotary Encoder/5 pin header.ipt
3d model/rotary-encoder-1.snapshot.8/Rotary Encoder/90d pin_header.ipt
3d model/rotary-encoder-1.snapshot.8/Rotary Encoder/OldVersions/mtg flange.0001.ipt
3d model/rotary-encoder-1.snapshot.8/Rotary Encoder/OldVersions/pins_encoder body_2.0001.ipt
3d model/rotary-encoder-1.snapshot.8/Rotary Encoder/OldVersions/pins_encoder body_2_2.0001.ipt
3d model/rotary-encoder-1.snapshot.8/Rotary Encoder/OldVersions/rotary encoder_chesr_2013.0010.iam
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

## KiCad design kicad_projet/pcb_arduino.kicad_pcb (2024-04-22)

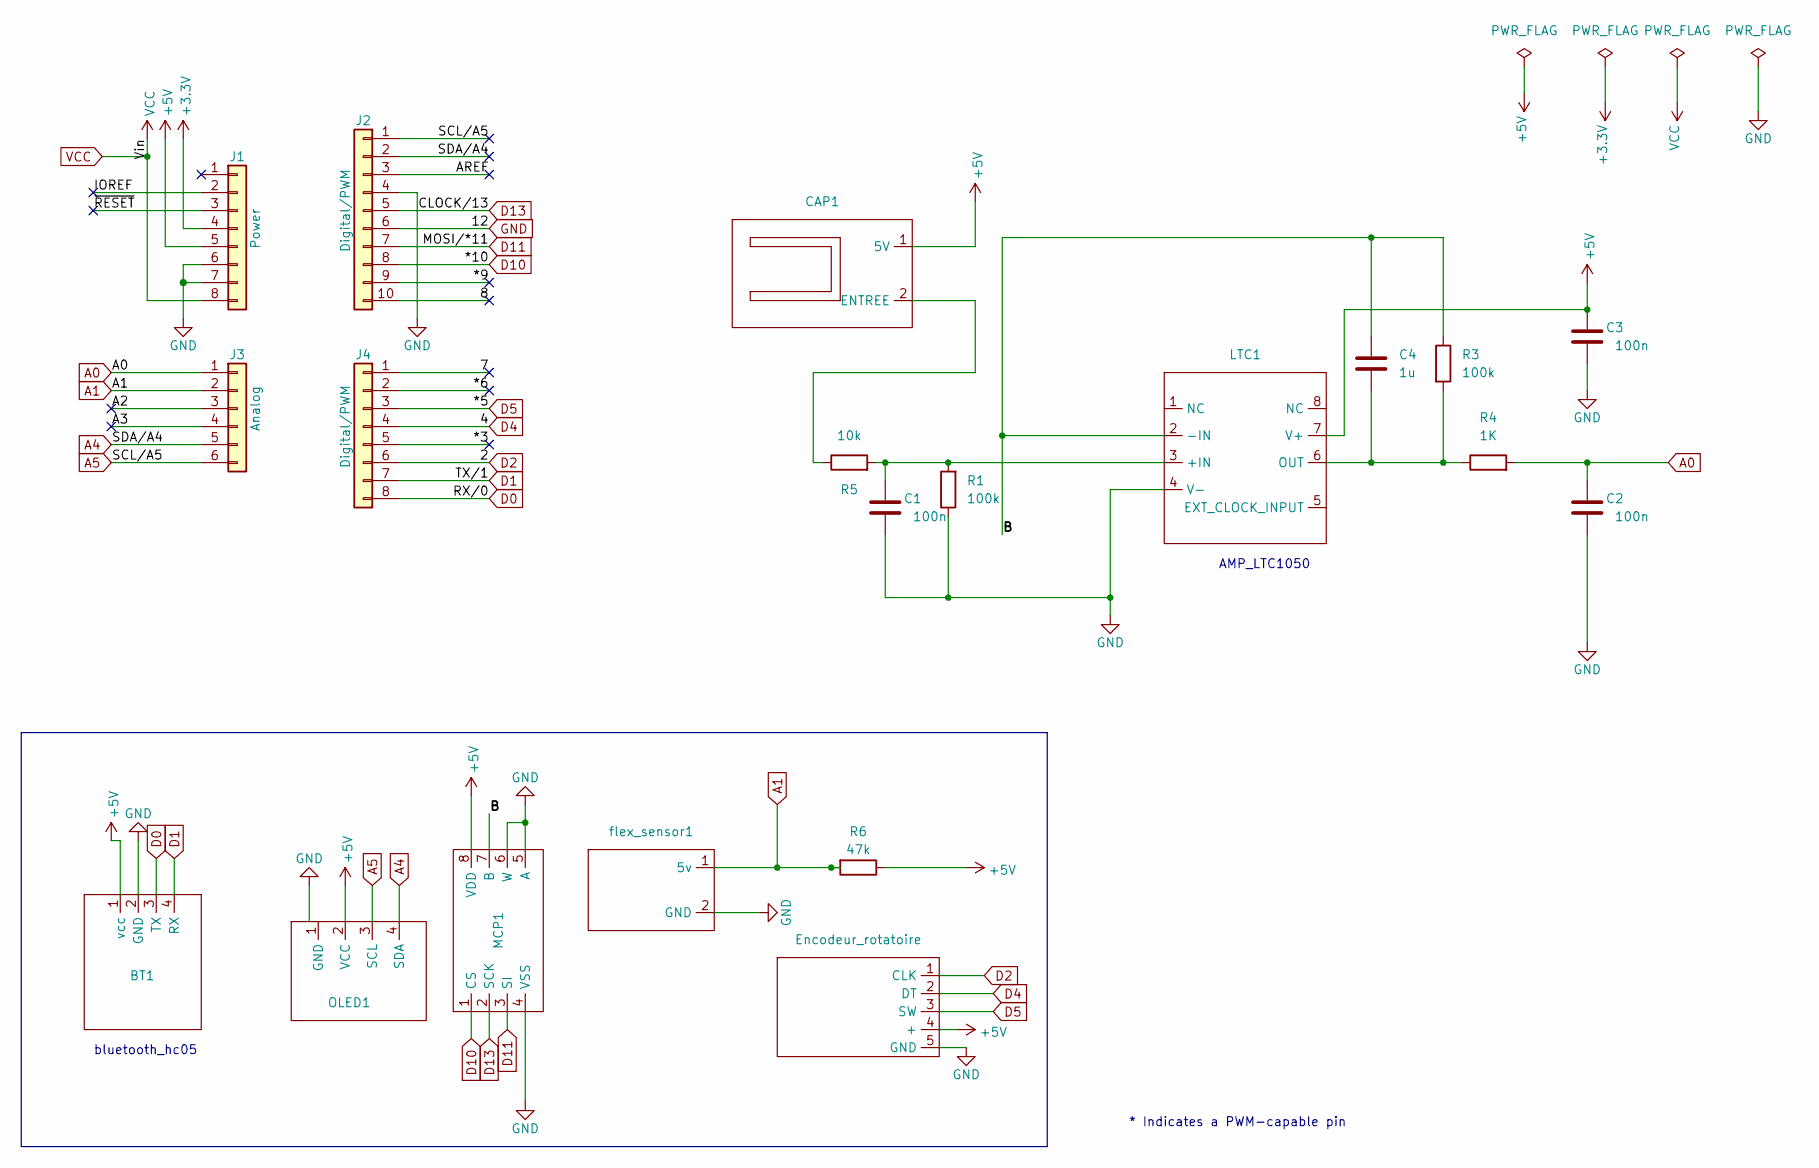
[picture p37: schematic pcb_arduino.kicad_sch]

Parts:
BT1: BT
C1, C2, C3: 100n; C_Disc_D4.3mm_W1.9mm_P5.00mm
C4: 1u; C_Rect_L7.2mm_W2.5mm_P5.00mm_FKS2_FKP2_MKS2_MKP2
CAP1: capteur
Encodeur_rotatoire: encodeur_rotatoire
J1: Power; PinSocket_1x08_P2.54mm_Vertical
J2: Digital/PWM; PinSocket_1x10_P2.54mm_Vertical
J3: Analog; PinSocket_1x06_P2.54mm_Vertical
J4: Digital/PWM; PinSocket_1x08_P2.54mm_Vertical
LTC1: LTC1050
MCP1: MCP41050
OLED1: OLED
R1, R3: 100k; R_Axial_DIN0207_L6.3mm_D2.5mm_P10.16mm_Horizontal
R4: 1K; R_Axial_DIN0207_L6.3mm_D2.5mm_P10.16mm_Horizontal
R5: 10k; R_Axial_DIN0207_L6.3mm_D2.5mm_P10.16mm_Horizontal
R6: 47k; R_Axial_DIN0207_L6.3mm_D2.5mm_P10.16mm_Horizontal
flex_sensor1: FLEX_SENSOR

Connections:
+3V3: J1.4
+5V: BT1.1 (vcc), C3.1, CAP1.1 (5V), Encodeur_rotatoire.4 (+), J1.5, LTC1.7 (V+), MCP1.8 (VDD), OLED1.2 (VCC), R6.1; also elsewhere on the board
/7: J4.1
/8: J2.10
/*3: J4.5
/*6: J4.2
/*9: J2.9
/A2: J3.3
/AREF: J2.3
/B: C4.1, LTC1.2 (-IN), MCP1.7 (B), R3.1
/IOREF: J1.2
/~RESET: J1.3
A0: C2.1, J3.1, R4.2
A1: J3.2, R6.2, flex_sensor1.1 (5v)
A4: J2.2, J3.5, OLED1.4 (SDA)
A5: J2.1, J3.6, OLED1.3 (SCL)
D0: BT1.3 (TX), J4.8
D1: BT1.4 (RX), J4.7
D2: Encodeur_rotatoire.1 (CLK), J4.6; also elsewhere on the board
D4: Encodeur_rotatoire.2 (DT), J4.4; also elsewhere on the board
D5: Encodeur_rotatoire.3 (SW), J4.3; also elsewhere on the board
D10: J2.8, MCP1.1 (CS)
D11: J2.7, MCP1.3 (SI)
D13: J2.5, MCP1.2 (SCK)
unnamed: CAP1.2 (ENTREE), R5.1
unnamed: C1.1, LTC1.3 (+IN), R1.2, R5.2
unnamed: C4.2, LTC1.6 (OUT), R3.2, R4.1
VCC: J1.8

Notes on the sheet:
bluetooth_hc05
* Indicates a PWM-capable pin
AMP_LTC1050

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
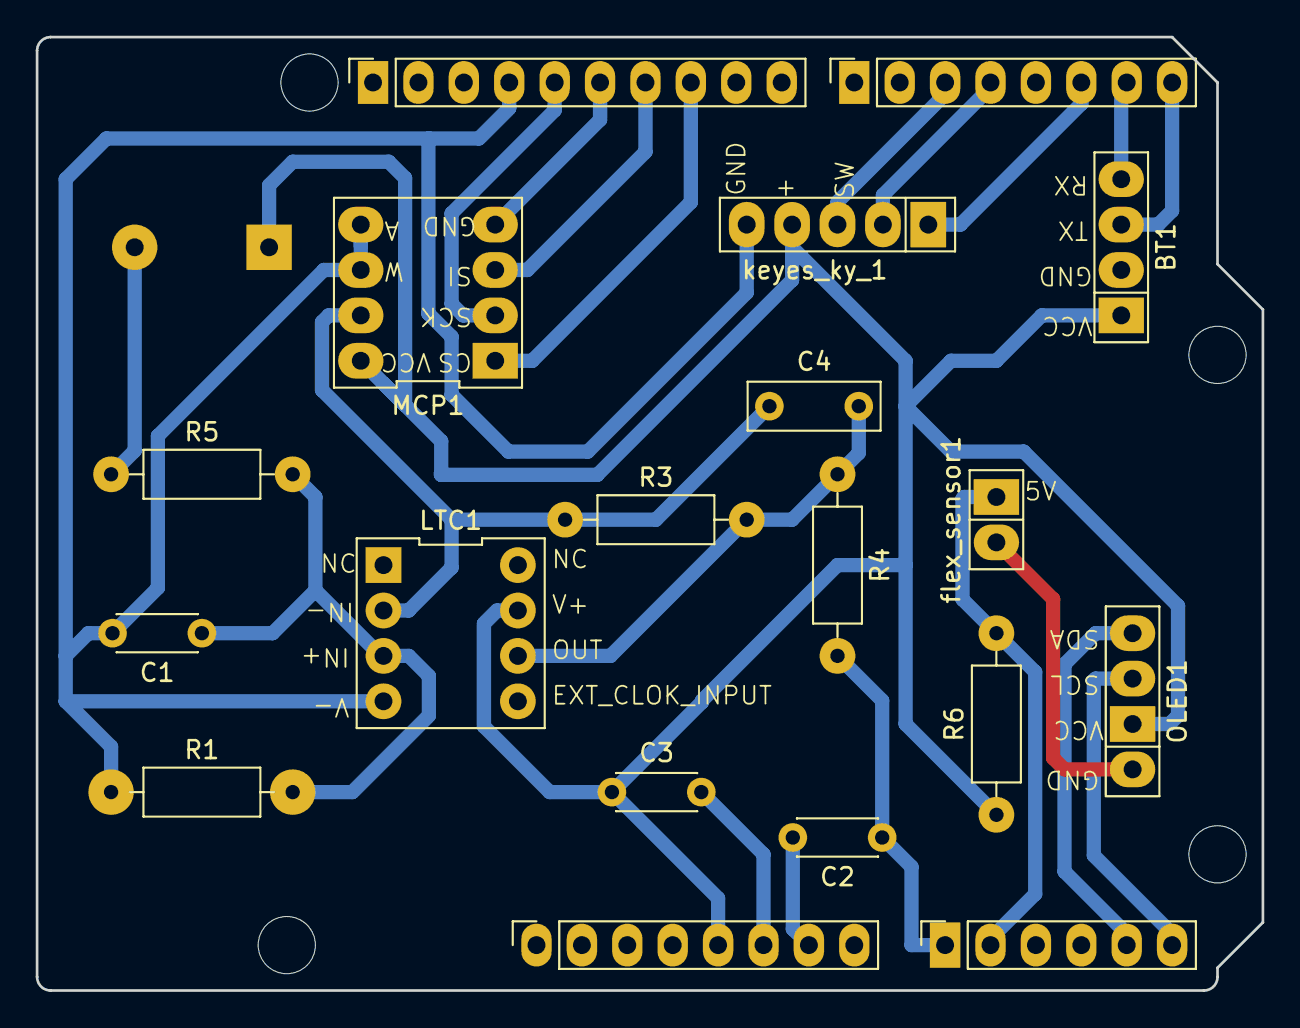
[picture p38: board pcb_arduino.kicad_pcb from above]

Board: 2 copper layers, 68.6 x 53.3 mm, 24 parts (1 on the bottom side), 18 nets.

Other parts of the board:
MH1, MH2, MH3, MH4: MountingHole_3.2mm
keyes_ky_1: encodeur_rotatoire

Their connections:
+5V: keyes_ky_1.4 (+); also elsewhere on the board
D2: keyes_ky_1.1 (CLK); also elsewhere on the board
D4: keyes_ky_1.2 (DT); also elsewhere on the board
D5: keyes_ky_1.3 (SW); also elsewhere on the board

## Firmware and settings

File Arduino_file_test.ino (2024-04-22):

 #include <Adafruit_SSD1306.h> // lib de l'ecran OLED
 #include <SPI.h>
 #define Resolution_vertical 0.0048828125
 int sensorValue_analog;
// ================ Initialisation Ecran OLED =================== ///
#define nombreDePixelsEnLargeur 128         // Taille de l'écran OLED, en pixel, au niveau de sa largeur
#define nombreDePixelsEnHauteur 64          // Taille de l'écran OLED, en pixel, au niveau de sa hauteur
#define brocheResetOLED         -1          // Reset de l'OLED partagé avec l'Arduino (d'où la valeur à -1, et non un numéro de pin)
#define adresseI2CecranOLED     0x3C        // Adresse de écran OLED sur le bus i2c 
Adafruit_SSD1306 ecranOLED(nombreDePixelsEnLargeur, nombreDePixelsEnHauteur, &Wire, brocheResetOLED);

// ================ Initialisation Encodeur Rotatoire =================== ///
#define encodeurpin_clk 2
#define encodeurpin_data 4
#define encodeurpin_switch 5
volatile unsigned int compteur = 0 ;
int etatprecedentDT;
int etatprecedentCLK;
void doEncoder();

// ================ Initialisation Flex Sensor =================== ///
const float VCC = 5;      
const float R_DIV = 9800.0;  // Resustance utilise pour diviser la tension 
const float flatResistance = 28000.0; // resistance when flat
const float bendResistance = 80000.0;  // resistance at 90 deg
const int flexpin = A1;
int bit_mask_pot = 16;
float R2;
float Gain;

// ==================== Initalisation Potentionmetre digitale ===================//
#define MCP_NOP 0b00000000 //Aucune commande execute
#define MCP_WRITE 0b00010001 //écrire les données contenues dans l'octet de données dans le potentionmètre 
#define MCP_SHTDWN 0b00100001 
const int ssMCPin = 10;
bool check_overload();

void SPIWrite(uint8_t cmd, uint8_t data, uint8_t ssPin) // SPI write the command and data to the MCP IC connected to the ssPin
{
  SPI.beginTransaction(SPISettings(14000000, MSBFIRST, SPI_MODE0)); //https://www.arduino.cc/en/Reference/SPISettings
  
  digitalWrite(ssPin, LOW); // SS pin low to select chip
  
  SPI.transfer(cmd);        // Send command code
  SPI.transfer(data);       // Send associated value
  
  digitalWrite(ssPin, HIGH);// SS pin high to de-select chip
  SPI.endTransaction();
}
// =========== Initilisation Module Bluetooth ========== //
  #include <stdlib.h>
  #include <string.h>
  #include <stdio.h>
  //#include <SoftwareSerial.h>
  
  byte serialRX; // variable de reception de donnée via RX
  byte serialTX; // variable de transmission de données via TX
  volatile byte RX = 0;
  int Gain_bit_mask;
  byte Option = 0;
  const int pushButton = 2;
  //#define rxPin 1  // Broche 10 en tant que RX, à raccorder sur TX du HC-05
  //#define txPin 0  // Broche 11 en tant que TX, à raccorder sur RX du HC-05
  //SoftwareSerial bluetooth(rxPin,txPin); // Définition du software serial pour le bluetooth


void setup() {
  // ========== Setup Port Série ========== //
  Serial.begin(9600); // initialize serial communication at 38400 bits per second:
  //Serial.println(F("Initialize System"));

  // ========== SETUP L'ECRAN OLED ==========//
  ecranOLED.clearDisplay(); 
  if(!ecranOLED.begin(SSD1306_SWITCHCAPVCC, adresseI2CecranOLED)){ while(1);  }    // Arrêt du programme (boucle infinie) en cas d'échec de l'initialisation
  ecranOLED.clearDisplay();   // Effaçage de la mémoire tampon de l'écran OLED
  delay(200);                            
  //Serial.println(F("OLED OK"));

  byte tailleDeCaractere = 1;
  ecranOLED.setTextSize(tailleDeCaractere);    

  //encodeur_rotatoire

  pinMode(encodeurpin_clk, INPUT);
  digitalWrite(encodeurpin_clk,HIGH);

  pinMode(encodeurpin_data, INPUT);
  digitalWrite(encodeurpin_data,HIGH);

  etatprecedentDT = digitalRead(encodeurpin_data);
  etatprecedentCLK = digitalRead(encodeurpin_clk);
  //Serial.println(F("ENCODEUR OK"));
  //flex sensor
   pinMode(flexpin, INPUT);

  // ============= SET UP POTENTIOMETRE DIGITAL ===========//
  pinMode (ssMCPin, OUTPUT); //select pin output
  digitalWrite(ssMCPin, HIGH); //SPI chip disabled
  SPI.begin(); 

  // ========== SET UP BLUETOOTH =========//
  pinMode(8, OUTPUT);

  
}


void loop() {
  //Lire la sens et la valeur de la compteur de l'encodeur rotatoire
  //Serial.println(compteur);
  doEncoder();
  // ==================== Potentiometre ===============
  SPIWrite(MCP_WRITE, bit_mask_pot, ssMCPin);
  // ***********************************************************************
  // Mesure la resistance de flex sensor et Lire la tension ADC à A0
  // ***********************************************************************
 
  int ADCflex = analogRead(flexpin);             // Lire la tension ADC de la pin A1
  float Vflex = ADCflex * Resolution_vertical;          // Calcul la tension ADC
  float Rflex = R_DIV * Vflex * (1 / (VCC - Vflex));     // Calcul la resistance de flex sensor
  sensorValue_analog = analogRead(A0);              // Lire la tension ADC de la pin A0 
  float sensorValue = sensorValue_analog * Resolution_vertical; // La tension ADC de la capteur graphite
  R2 = (50000 / 256) * bit_mask_pot + 125; 
  Gain = (1 + 100000 / R2) * 10 / 11;
  float R_sensor = (VCC / sensorValue) * 98000 * (1 + (98000/R2)) - 98000 - 9800;

  // ***********************************************************************
  // Envoyer les valeur de resistance à la module Bluetooth
  // ***********************************************************************
  int i=0;
  char received_message[32]={0};
  char gain[4] = {0};    
  do{
    received_message[i++]=Serial.read();
    delay(4);       
    }while (Serial.available() >0) ;
  
  // Ajuster le gain de l'AmpliOp 
  if (strstr(received_message,"Gain"))
  {  
    for (int k = 0 ;k < 4; k++){
    gain[k] = received_message[k + 4];
  }
    bit_mask_pot = atoi(gain);
  }

  // Mettre à jour le gain actuel sur l'interface
   if (strstr(received_message,"Update"))
  {  
    Serial.print("update ");
    Serial.println(bit_mask_pot);
  }

  if (strstr(received_message,"Flex")){
    if (check_overload(ADCflex)){
       Serial.print("over");
    }
    else{
    Serial.print(Rflex/1000);
    Serial.print(" ");
    Serial.println(ADCflex);
    Serial.print(' ');
    }
  }

  if (strstr(received_message, "Capteur"))
  {
    
    if( check_overload( sensorValue_analog )){
      Serial.print("over");
    }
    else{
    Serial.print(R_sensor/1000000);
    Serial.print(' ');
    Serial.println(sensorValue_analog);
    Serial.print(' ');
    }
  }

  // ***********************************************************************
  // Affichage OLED selon Encodeur Rotatoire
  // ***********************************************************************
  ecranOLED.clearDisplay();                                   // Effaçage de l'intégralité du buffer
  ecranOLED.setCursor(0, 0); 
  ecranOLED.setTextColor(SSD1306_WHITE, SSD1306_BLACK);
  if (compteur % 2 == 0){
  ecranOLED.print("CAPTEUR: \n");
  ecranOLED.println("");
  ecranOLED.println("Resistance: ");
  ecranOLED.print(R_sensor/1000);
  ecranOLED.println(" kOhm");
  ecranOLED.println("");
  ecranOLED.print("Tension ADC: ");
  ecranOLED.println(sensorValue);
  ecranOLED.println("");
  ecranOLED.print("Gain ");
  ecranOLED.println (1 +(98000/(bit_mask_pot*195.31+125)));


  }
  else{
  ecranOLED.print("Flex: \n");
  ecranOLED.println("");
  ecranOLED.println("Resistance: ");
  ecranOLED.print(Rflex);}
  ecranOLED.display();        
  }                    


void doEncoder() {
  int etatactuelleDT = digitalRead(encodeurpin_data);
  int etatactuelleCLK = digitalRead(encodeurpin_clk);
  if (etatactuelleCLK != etatprecedentCLK){
    etatprecedentCLK  = etatactuelleCLK;
    if (etatactuelleCLK == LOW){
      if(etatactuelleCLK != etatactuelleDT){
        compteur ++;
      }
      else{
        compteur --;
        }
      }
    }
  }

bool check_overload(int bit_check){
  if  (bit_check > 980 && bit_check < 1024 ){
    Serial.print("over");
  }
}  

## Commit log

2024-04-22 Arduino code
2024-04-22 Update README.md
    Ajouter les titres
2024-06-07 update 3d model
    [5 pin header.ipt, 5 pin header.stp, 90d pin_header.ipt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]
